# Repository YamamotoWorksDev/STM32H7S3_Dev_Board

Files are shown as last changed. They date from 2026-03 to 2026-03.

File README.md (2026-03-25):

# STM32H7S3 Development Board (rev.C)
This board is a development board featuring the STM32H7S3Z8T MCU.

## How to buy
- [Tindie(International)](https://www.tindie.com/products/41582/)
- [BASE(Japan)](https://miyworks.base.shop/items/135242611)

## Specifications
- MCU specs.
  - STMicroelectronics [STM32H7S3Z8T](https://www.st.com/en/microcontrollers-microprocessors/stm32h7s3z8.html)(Arm Cortex-M7 Core/600MHz max)
  - External Crystal Oscilator(24MHz)
  - External FLASH(256Mbits OctoSPI)
  - USB type-C(USB2.0 High-Speed supported)
  - [UF2 bootloader](https://github.com/yamamo2shun1/JUMBLEQ/tree/main/STM32CubeIDE/MX25UW25645GXDI00_STM32H7S3Z8T)

- DSP specs.
  - Analog Devices [ADAU1466](https://www.analog.com/en/products/adau1466.html)(SigmaDSP Core/294.912MHz max)

## Pinout
JUMBLEQ_main_pinout_revC

## Size


## Byte Options
XSPI1_HSLV
DTCM_AXI_SHARE

## Application Example
- [JUMBLEQ](https://github.com/yamamo2shun1/JUMBLEQ)

## Photo
overall
top

## License
The hardware design files in this repository are licensed under the
**CERN Open Hardware Licence Version 2 - Permissive (CERN-OHL-P-2.0)**.

Unless otherwise stated, the following are treated as hardware design files covered by CERN-OHL-P-2.0:

- KiCad schematic files
- PCB layout files

A copy of the license text is provided in the `LICENSE` file.

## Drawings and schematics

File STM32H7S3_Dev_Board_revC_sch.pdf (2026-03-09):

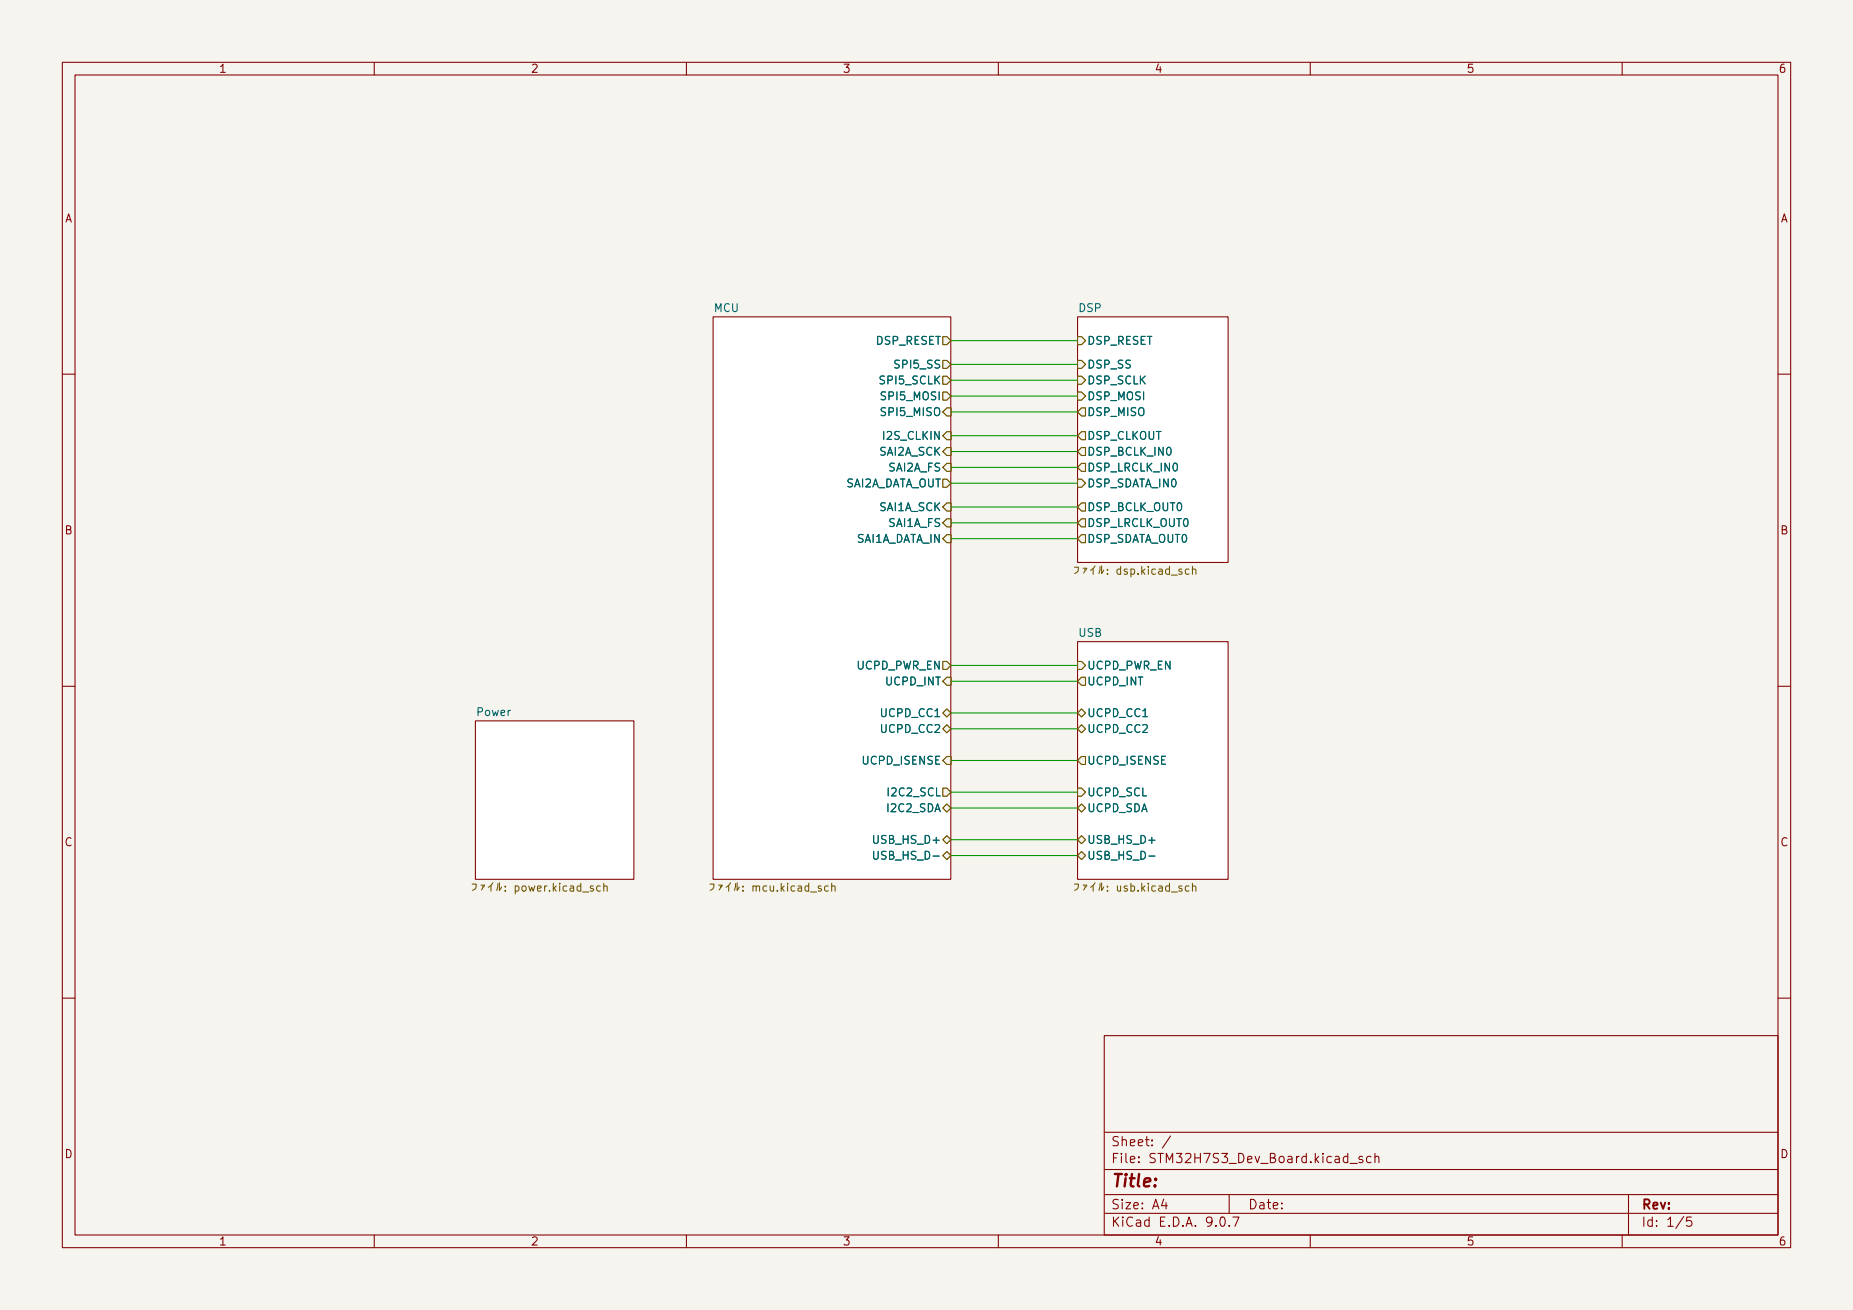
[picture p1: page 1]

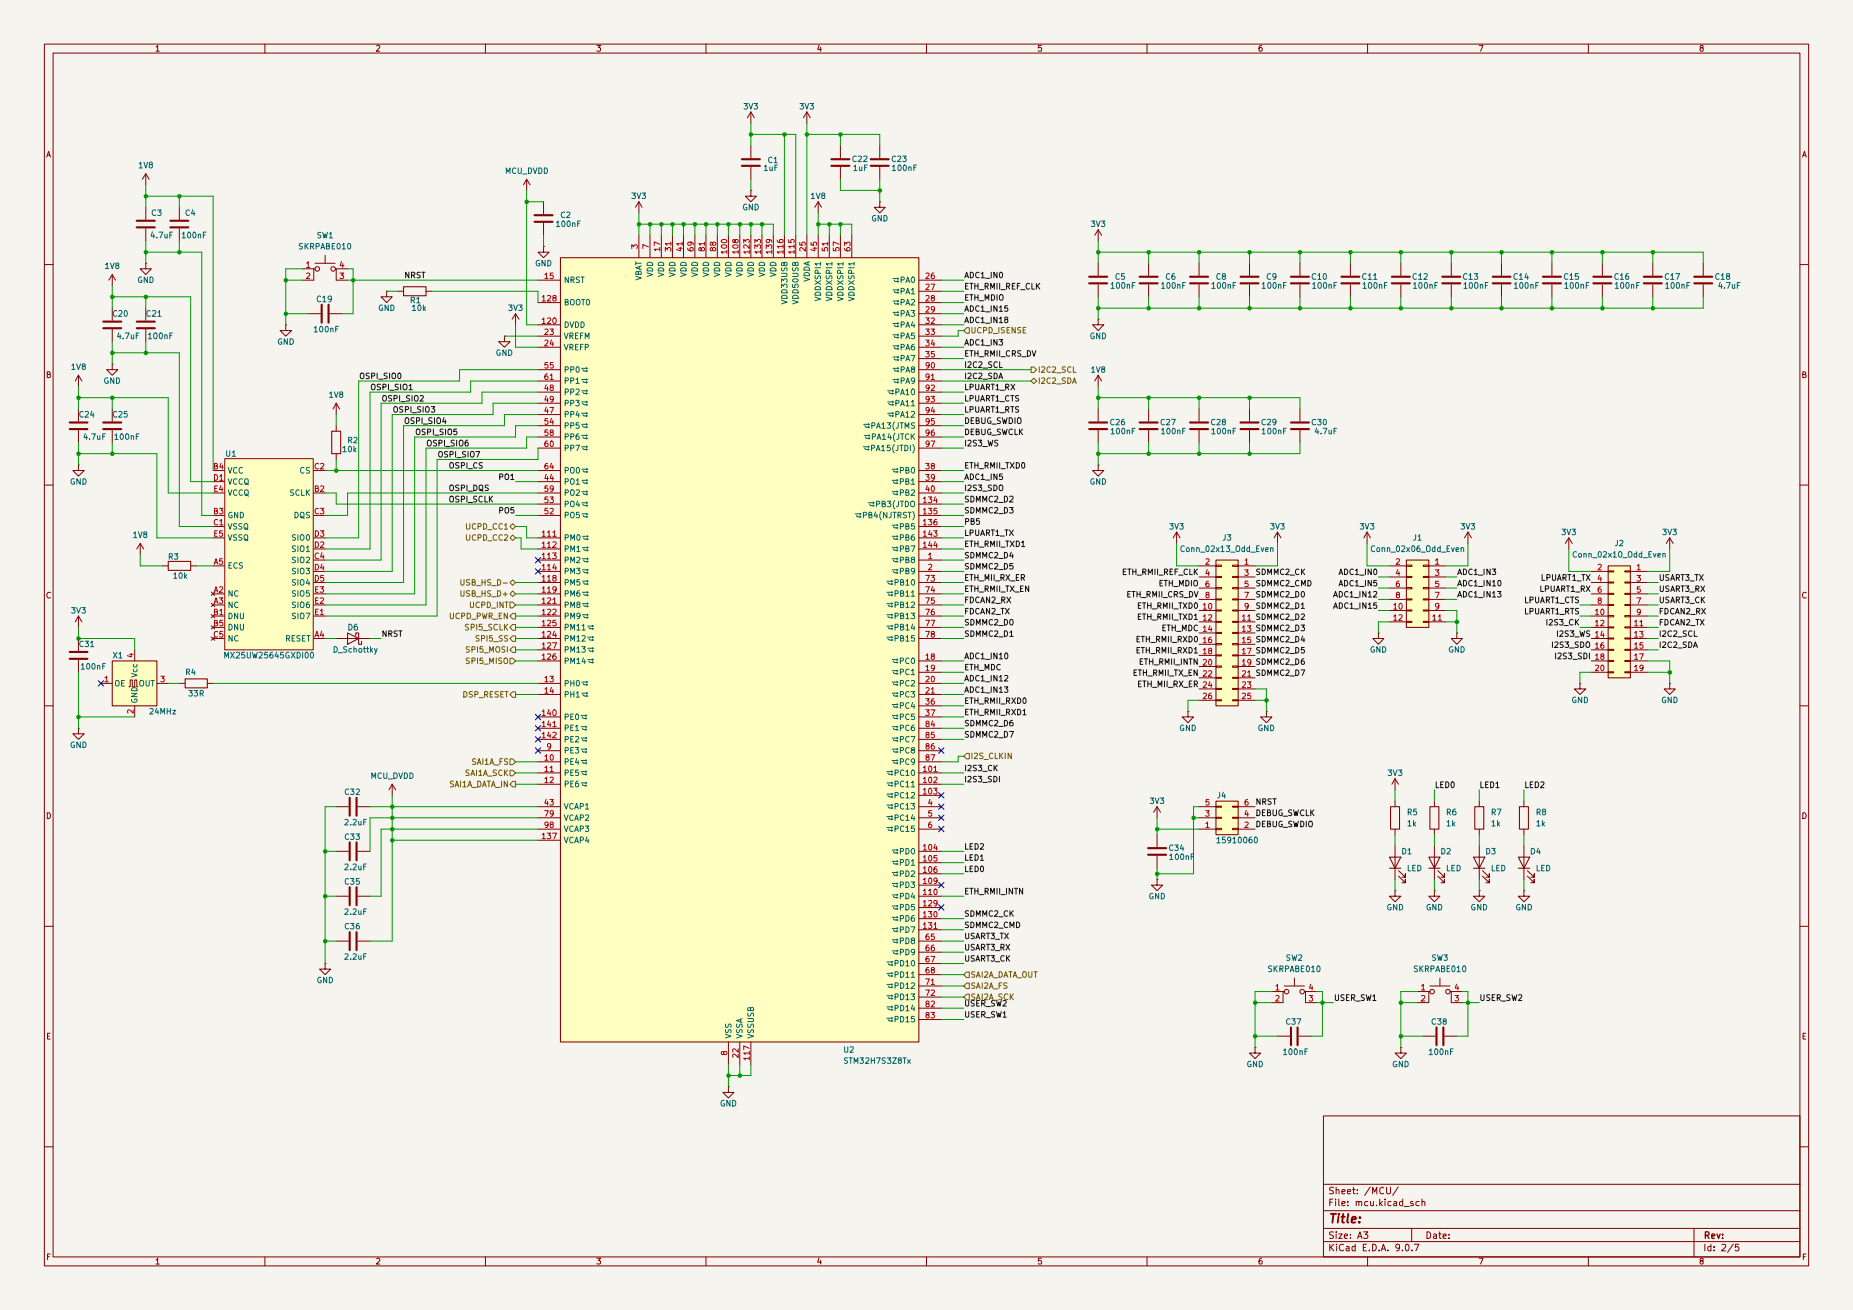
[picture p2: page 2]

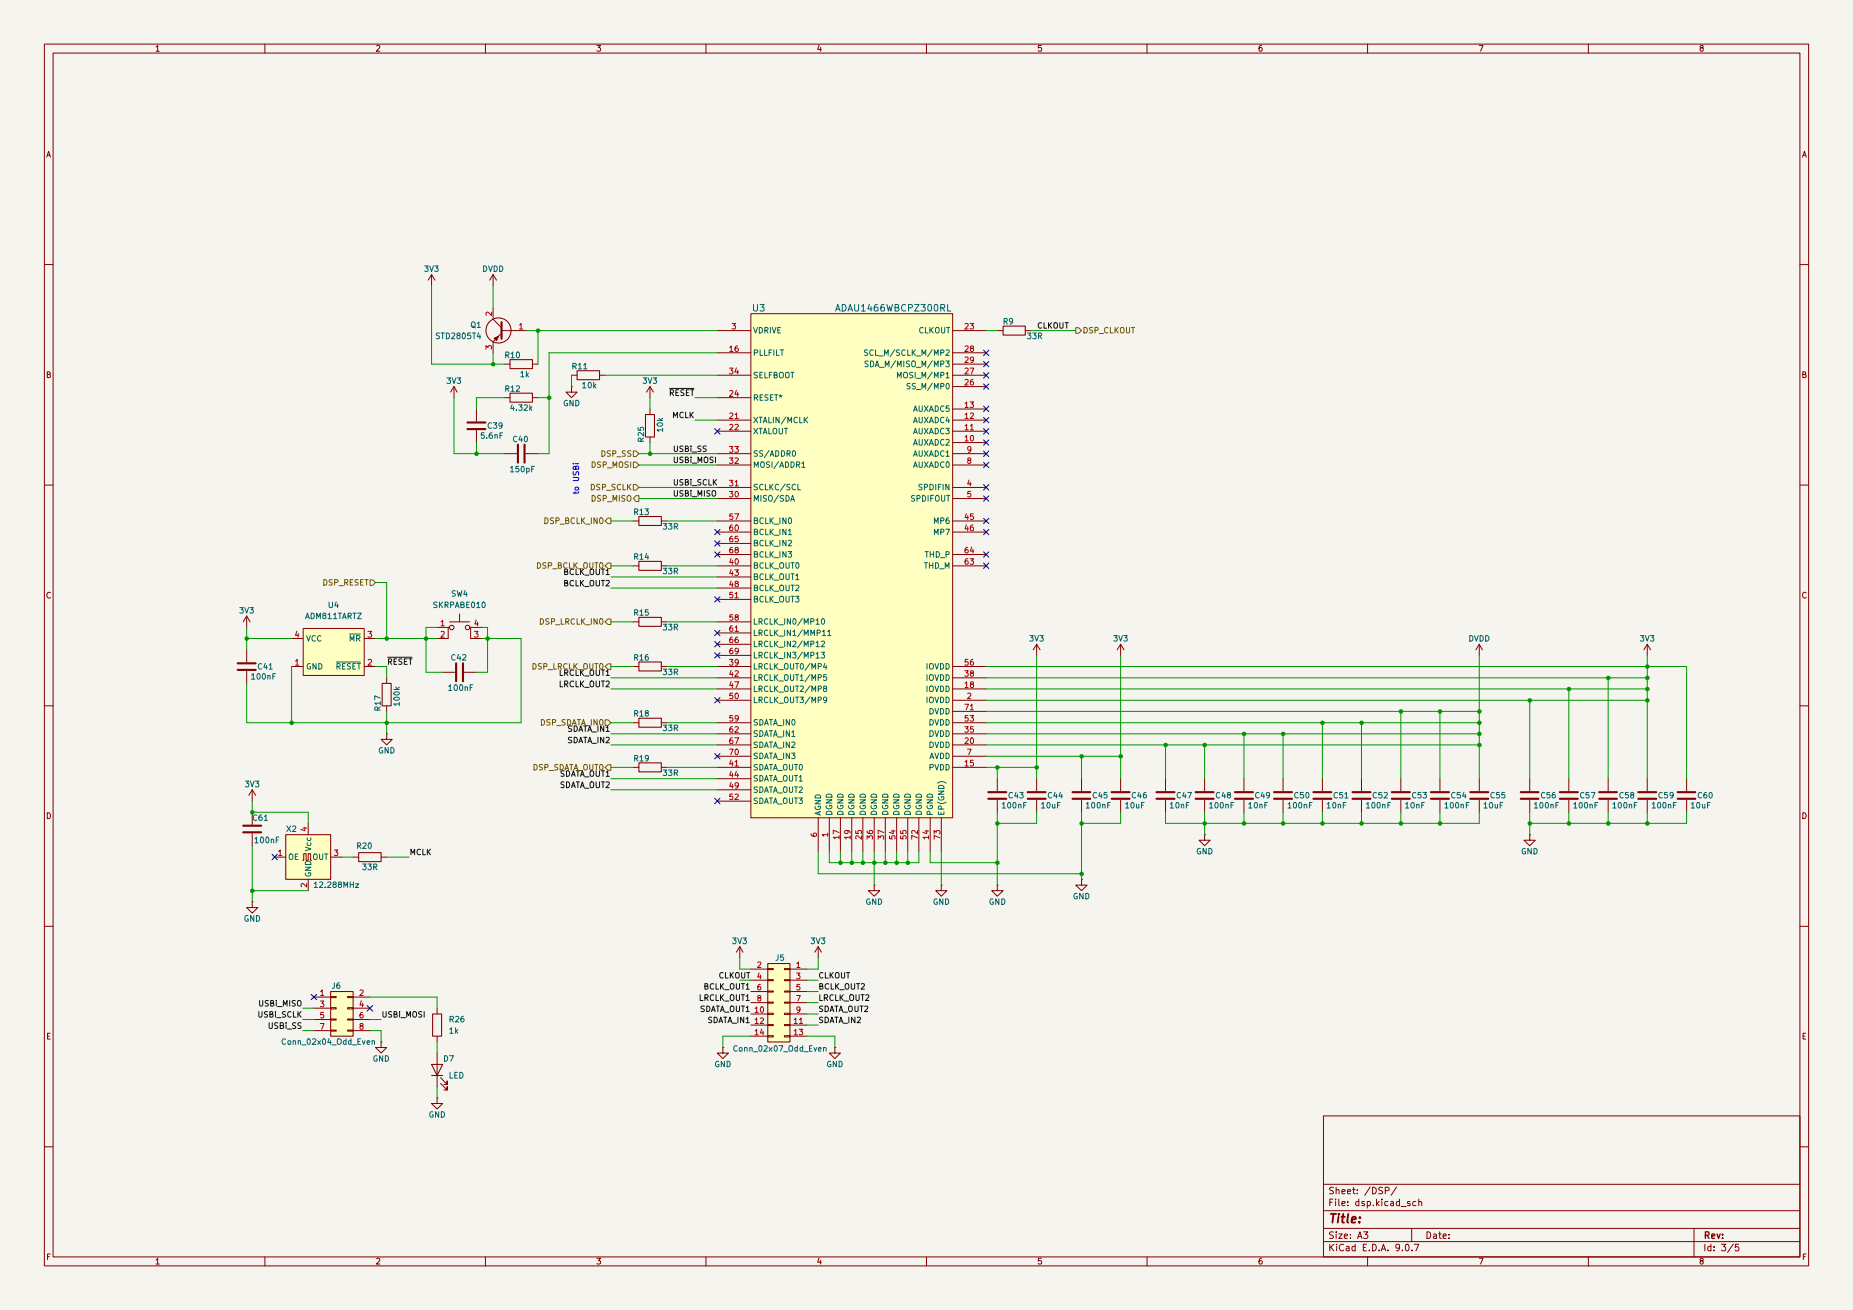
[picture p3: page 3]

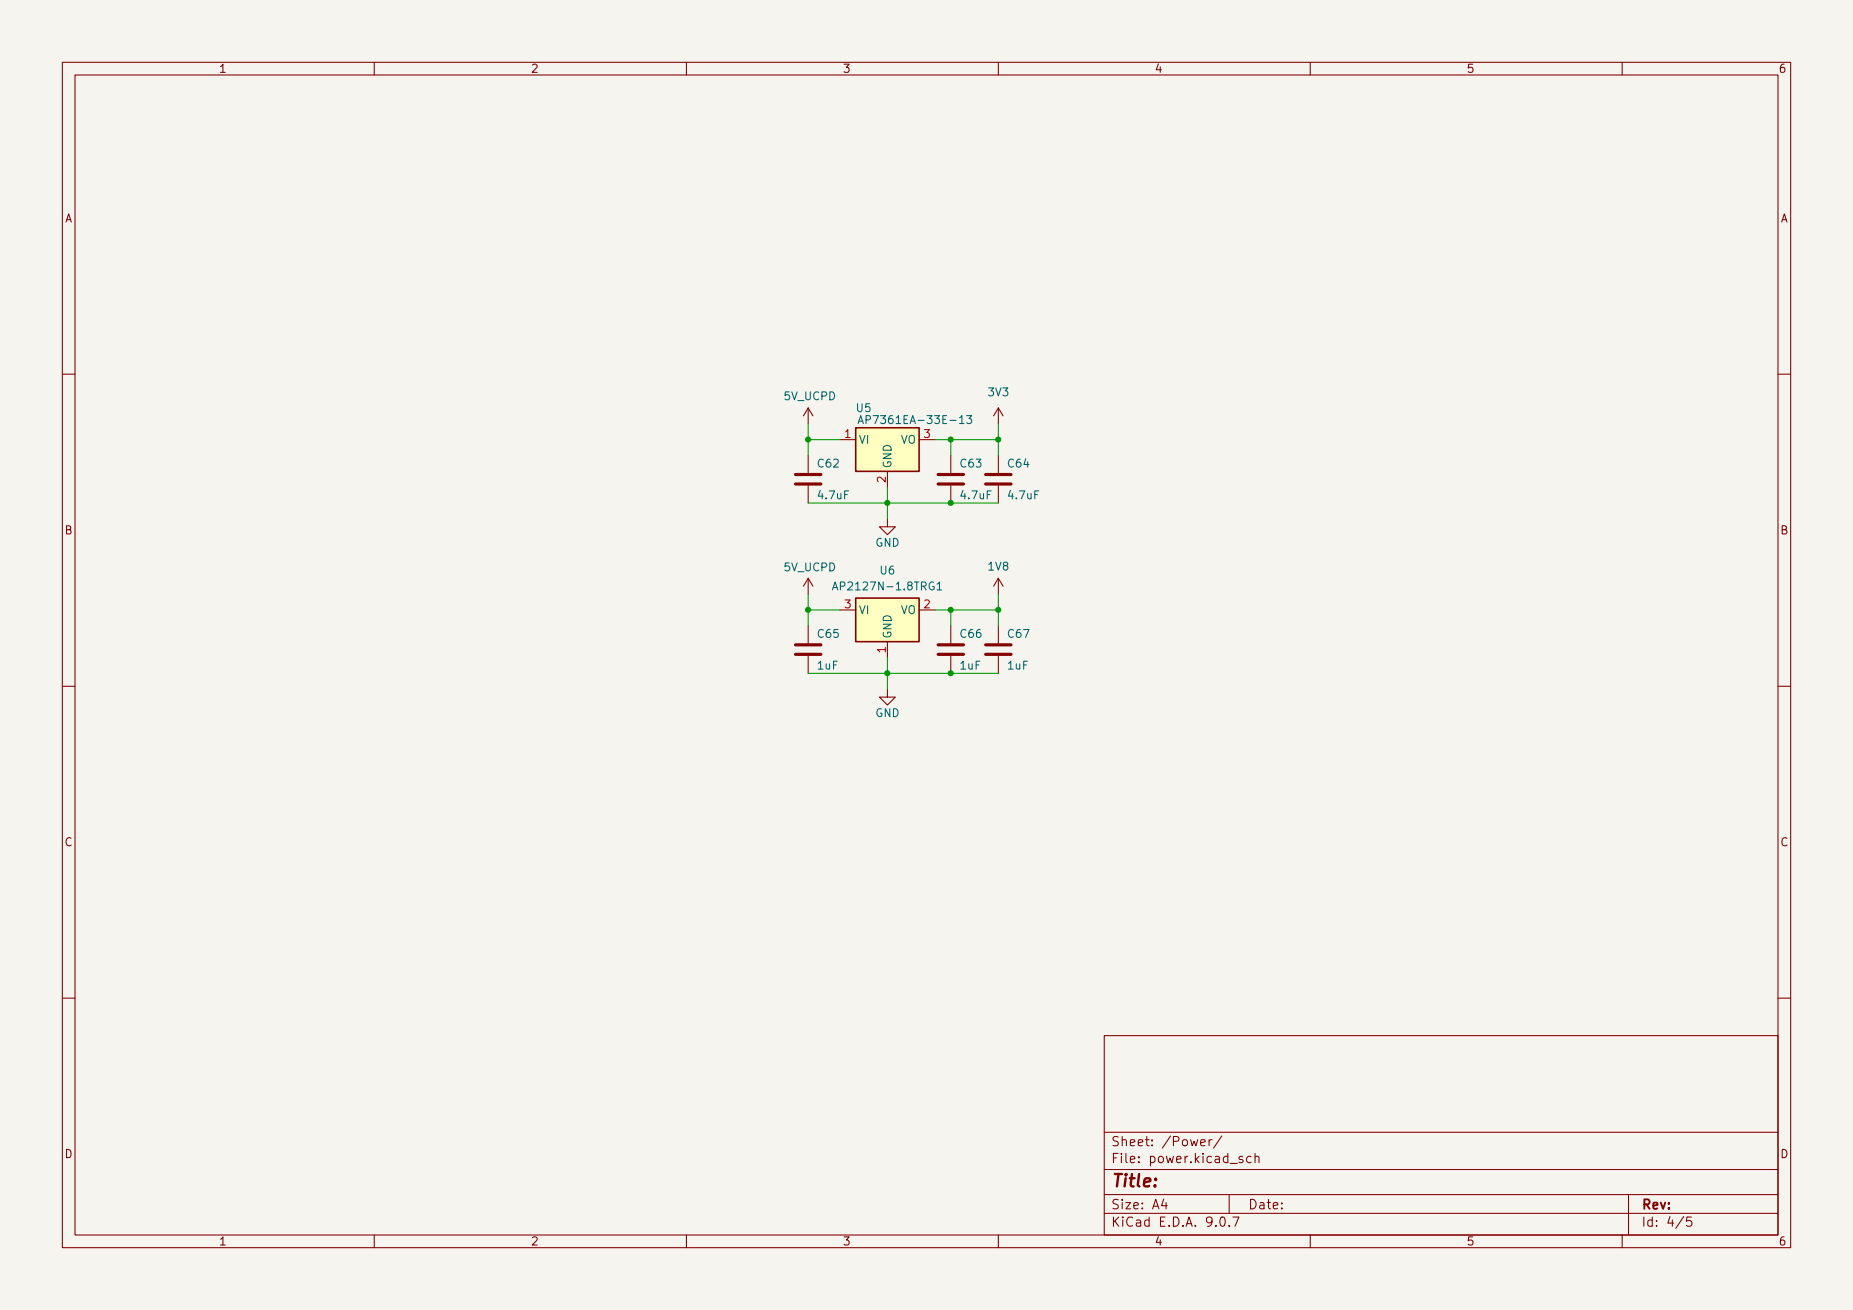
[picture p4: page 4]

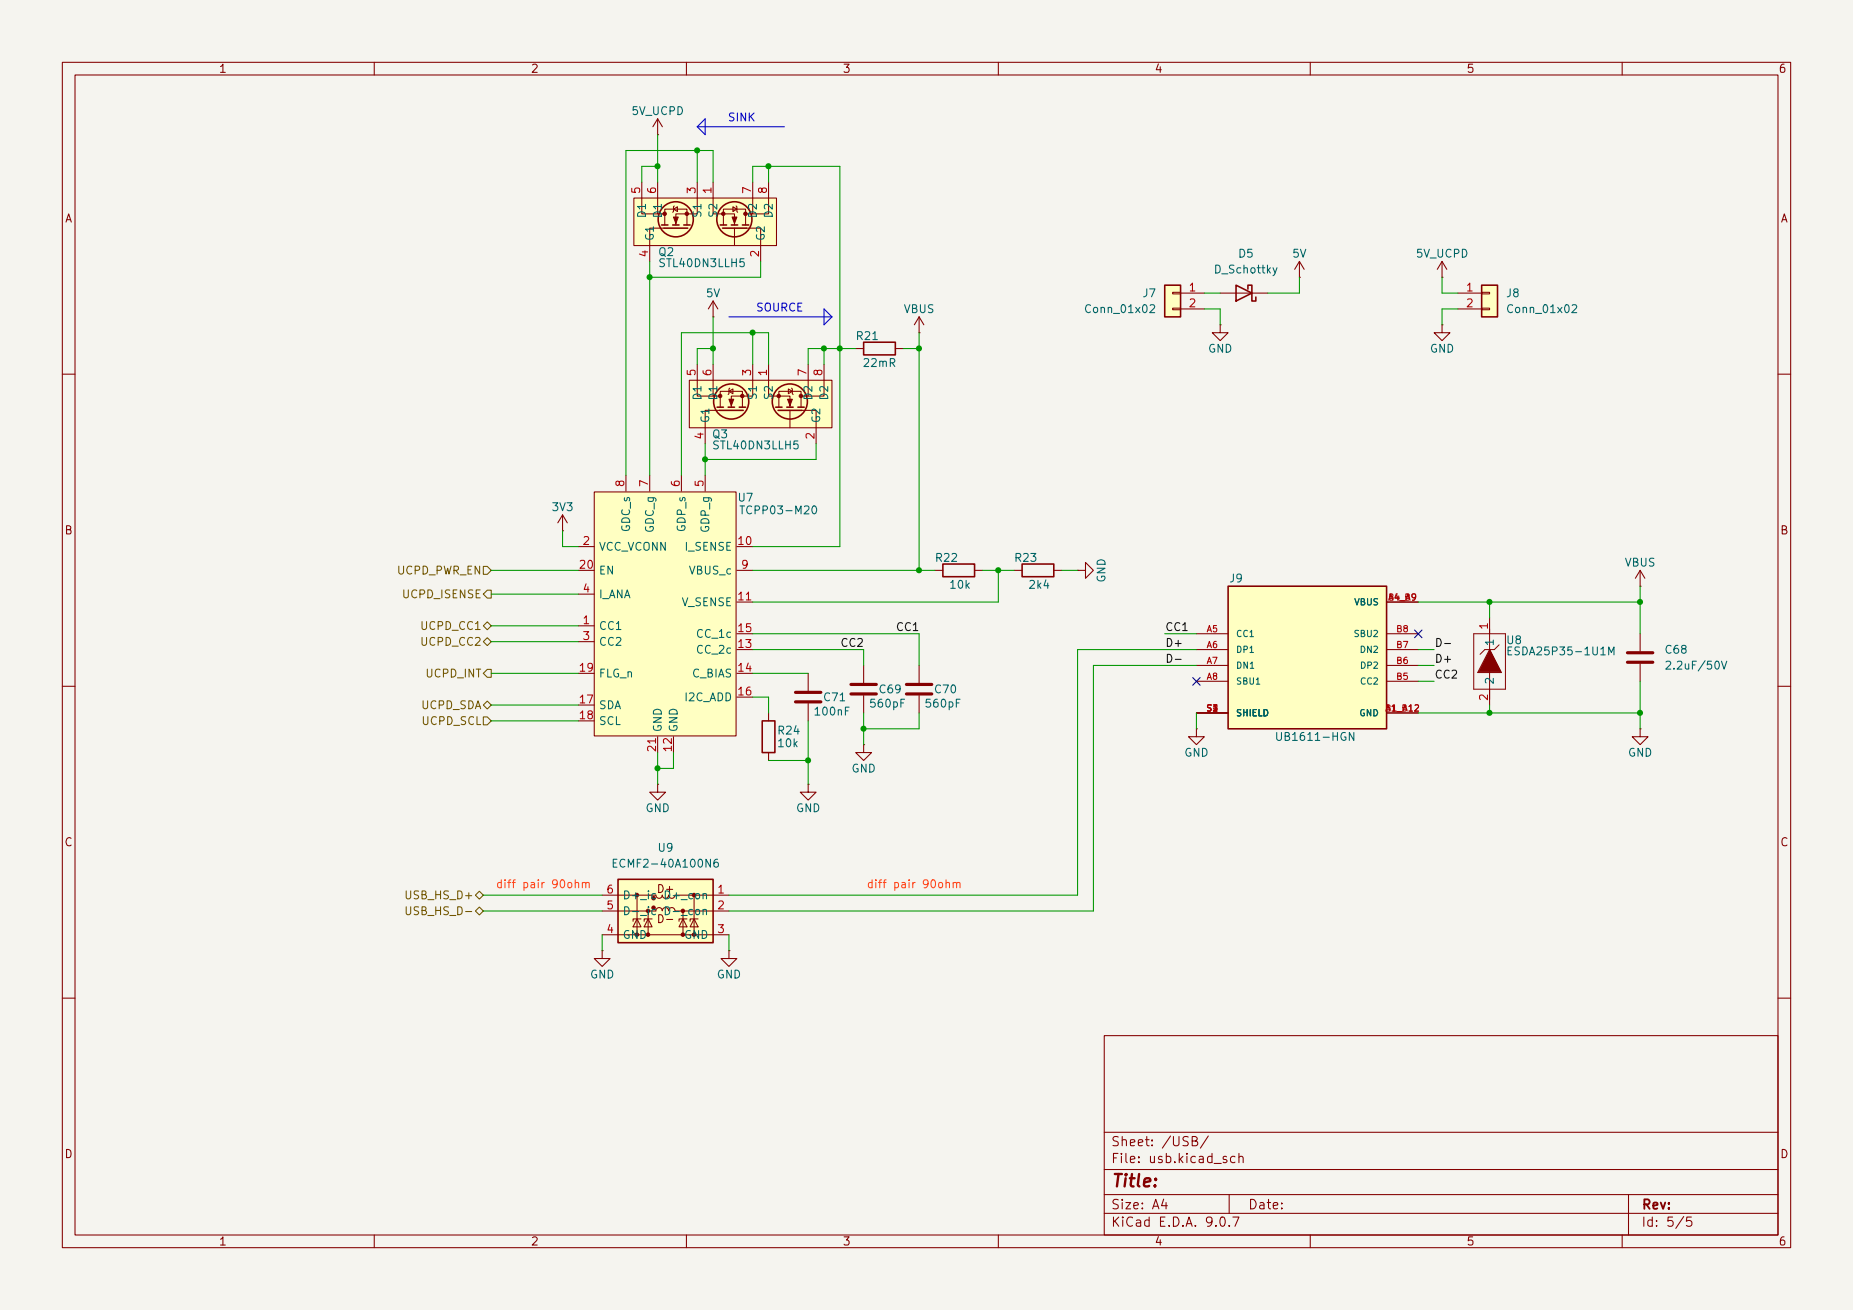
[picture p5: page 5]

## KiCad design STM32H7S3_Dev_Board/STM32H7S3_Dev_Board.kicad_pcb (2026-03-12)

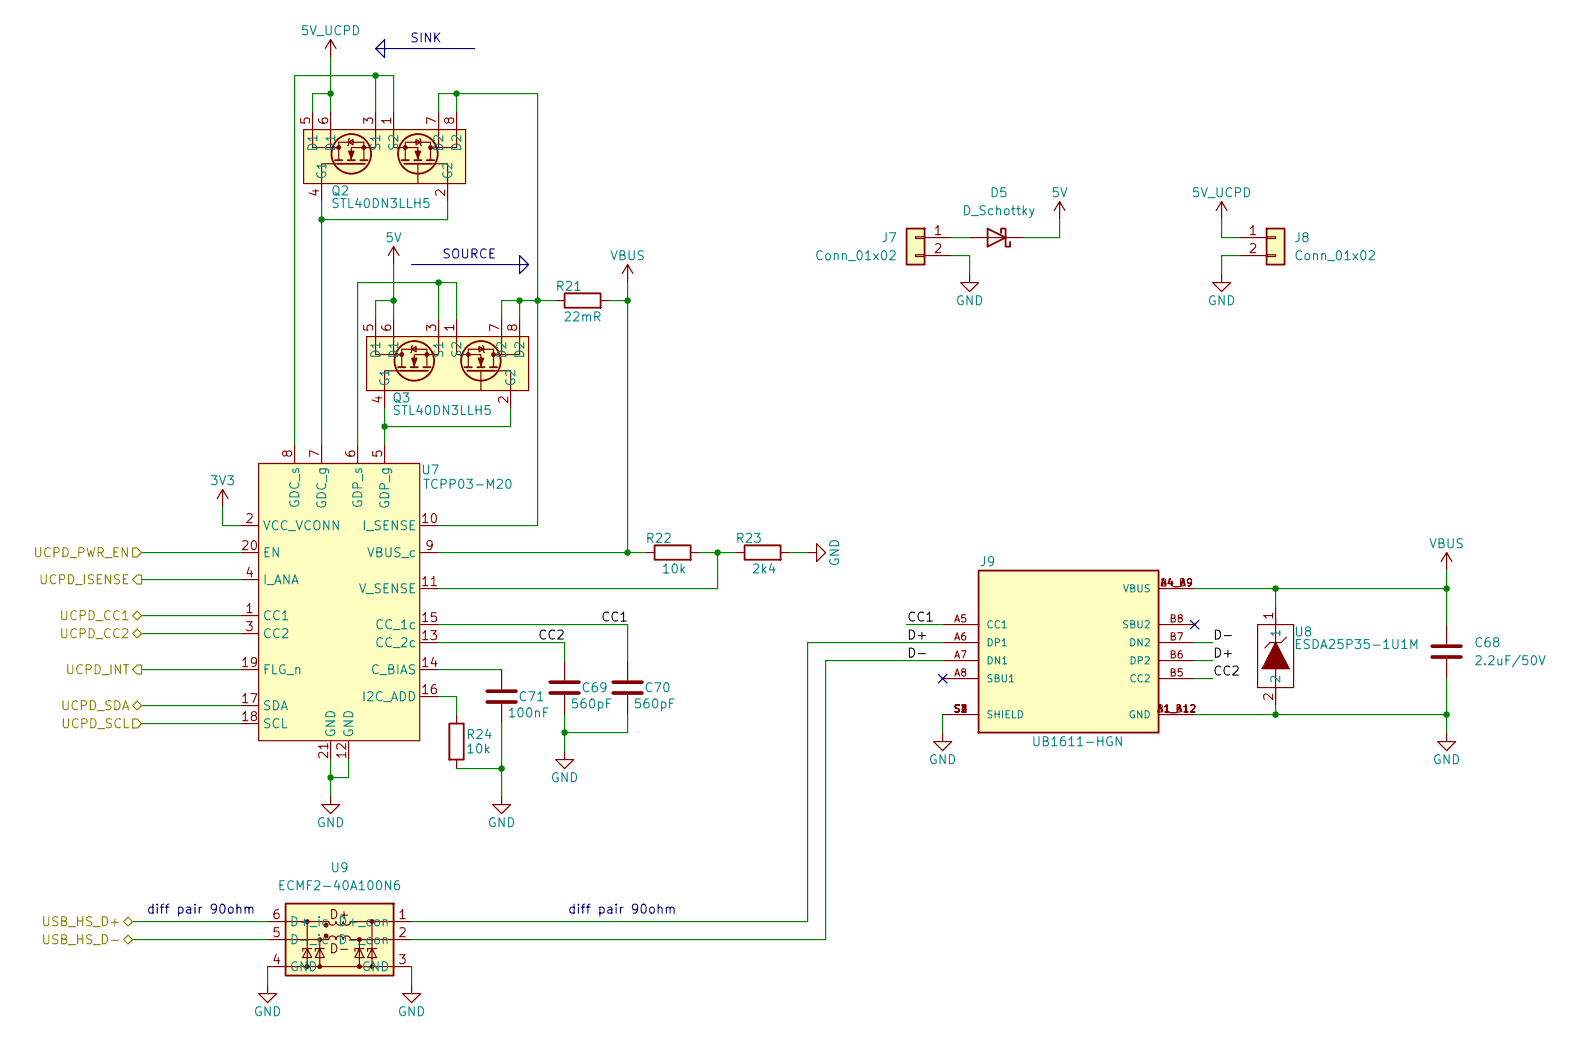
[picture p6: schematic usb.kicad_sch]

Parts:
C68: 2.2uF/50V; C_0603_1608Metric
C69, C70: 560pF; C_0201_0603Metric
C71: 100nF; C_0201_0603Metric
D5: D_Schottky; D_PowerDI-123
J7, J8: Conn_01x02; JST_PH_S2B-PH-K_1x02_P2.00mm_Horizontal
J9: UB1611-HGN; Gangyuan_UB1611-HGN; PARTREV B
Q2, Q3: STL40DN3LLH5; SON_DN3LLH5_STM
R21: 22mR; R_0603_1608Metric
R22, R24: 10k; R_0201_0603Metric
R23: 2k4; R_0201_0603Metric
U7: TCPP03-M20; QFN-20L_4.0X4.0X0.75_STM
U8: ESDA25P35-1U1M; QFN1610_STM
U9: ECMF2-40A100N6; QFN6L_ECMF2_STM

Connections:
3V3: U7.2 (VCC_VCONN); also elsewhere on the board
5V: D5.1 (K), Q3.5 (D1), Q3.6 (D1)
5V_UCPD: J8.1, Q2.5 (D1), Q2.6 (D1); also elsewhere on the board
/MCU/I2C2_SCL: U7.18 (SCL); also elsewhere on the board
/MCU/I2C2_SDA: U7.17 (SDA); also elsewhere on the board
/MCU/UCPD_CC1: U7.1 (CC1); also elsewhere on the board
/MCU/UCPD_CC2: U7.3 (CC2); also elsewhere on the board
/MCU/UCPD_INT: U7.19 (FLG_n); also elsewhere on the board
/MCU/UCPD_ISENSE: U7.4 (I_ANA); also elsewhere on the board
/MCU/UCPD_PWR_EN: U7.20 (EN); also elsewhere on the board
/MCU/USB_HS_D+: U9.6 (D+_ic); also elsewhere on the board
/MCU/USB_HS_D-: U9.5 (D-_ic); also elsewhere on the board
/USB/CC1: C70.1, J9.A5 (CC1), U7.15 (CC_1c)
/USB/CC2: C69.1, J9.B5 (CC2), U7.13 (CC_2c)
/USB/D+: J9.A6 (DP1), J9.B6 (DP2), U9.1 (D+_con)
/USB/D-: J9.A7 (DN1), J9.B7 (DN2), U9.2 (D-_con)
GND: C68.2, C69.2, C70.2, C71.2, J7.2, J8.2, J9.A1_B12 (GND), J9.B1_A12 (GND), J9.S1 (SHIELD), J9.S2 (SHIELD), J9.S3 (SHIELD), J9.S4 (SHIELD), R23.2, R24.2, U7.12 (GND), U7.21 (GND), U8.2, U9.3 (GND), U9.4 (GND); also elsewhere on the board
unnamed: D5.2 (A), J7.1
unnamed: Q2.2 (G2), Q2.4 (G1), U7.7 (GDC_g)
unnamed: Q2.1 (S2), Q2.3 (S1), U7.8 (GDC_s)
unnamed: Q3.2 (G2), Q3.4 (G1), U7.5 (GDP_g)
unnamed: Q3.1 (S2), Q3.3 (S1), U7.6 (GDP_s)
unnamed: C71.1, U7.14 (C_BIAS)
unnamed: R24.1, U7.16 (I2C_ADD)
unnamed: Q2.7 (D2), Q2.8 (D2), Q3.7 (D2), Q3.8 (D2), R21.1, U7.10 (I_SENSE)
unnamed: R22.2, R23.1, U7.11 (V_SENSE)
VBUS: C68.1, J9.A4_B9 (VBUS), J9.B4_A9 (VBUS), R21.2, R22.1, U7.9 (VBUS_c), U8.1

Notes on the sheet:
SOURCE
diff pair 90ohm
SINK

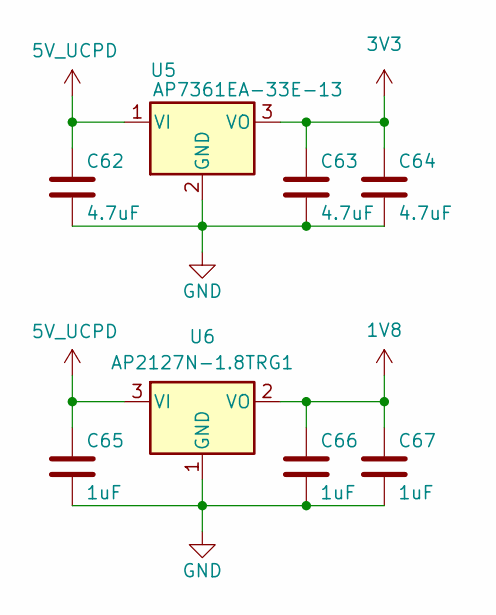
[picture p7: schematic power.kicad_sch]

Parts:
C62, C63, C64: 4.7uF; C_0603_1608Metric
C65, C66, C67: 1uF; C_0603_1608Metric
U5: AP7361EA-33E-13; SOT-223-3_TabPin2
U6: AP2127N-1.8TRG1; SOT-23

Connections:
1V8: C66.1, C67.1, U6.2 (VO); also elsewhere on the board
3V3: C63.1, C64.1, U5.3 (VO); also elsewhere on the board
5V_UCPD: C62.1, C65.1, U5.1 (VI), U6.3 (VI); also elsewhere on the board
GND: C62.2, C63.2, C64.2, C65.2, C66.2, C67.2, U5.2 (GND), U6.1 (GND); also elsewhere on the board

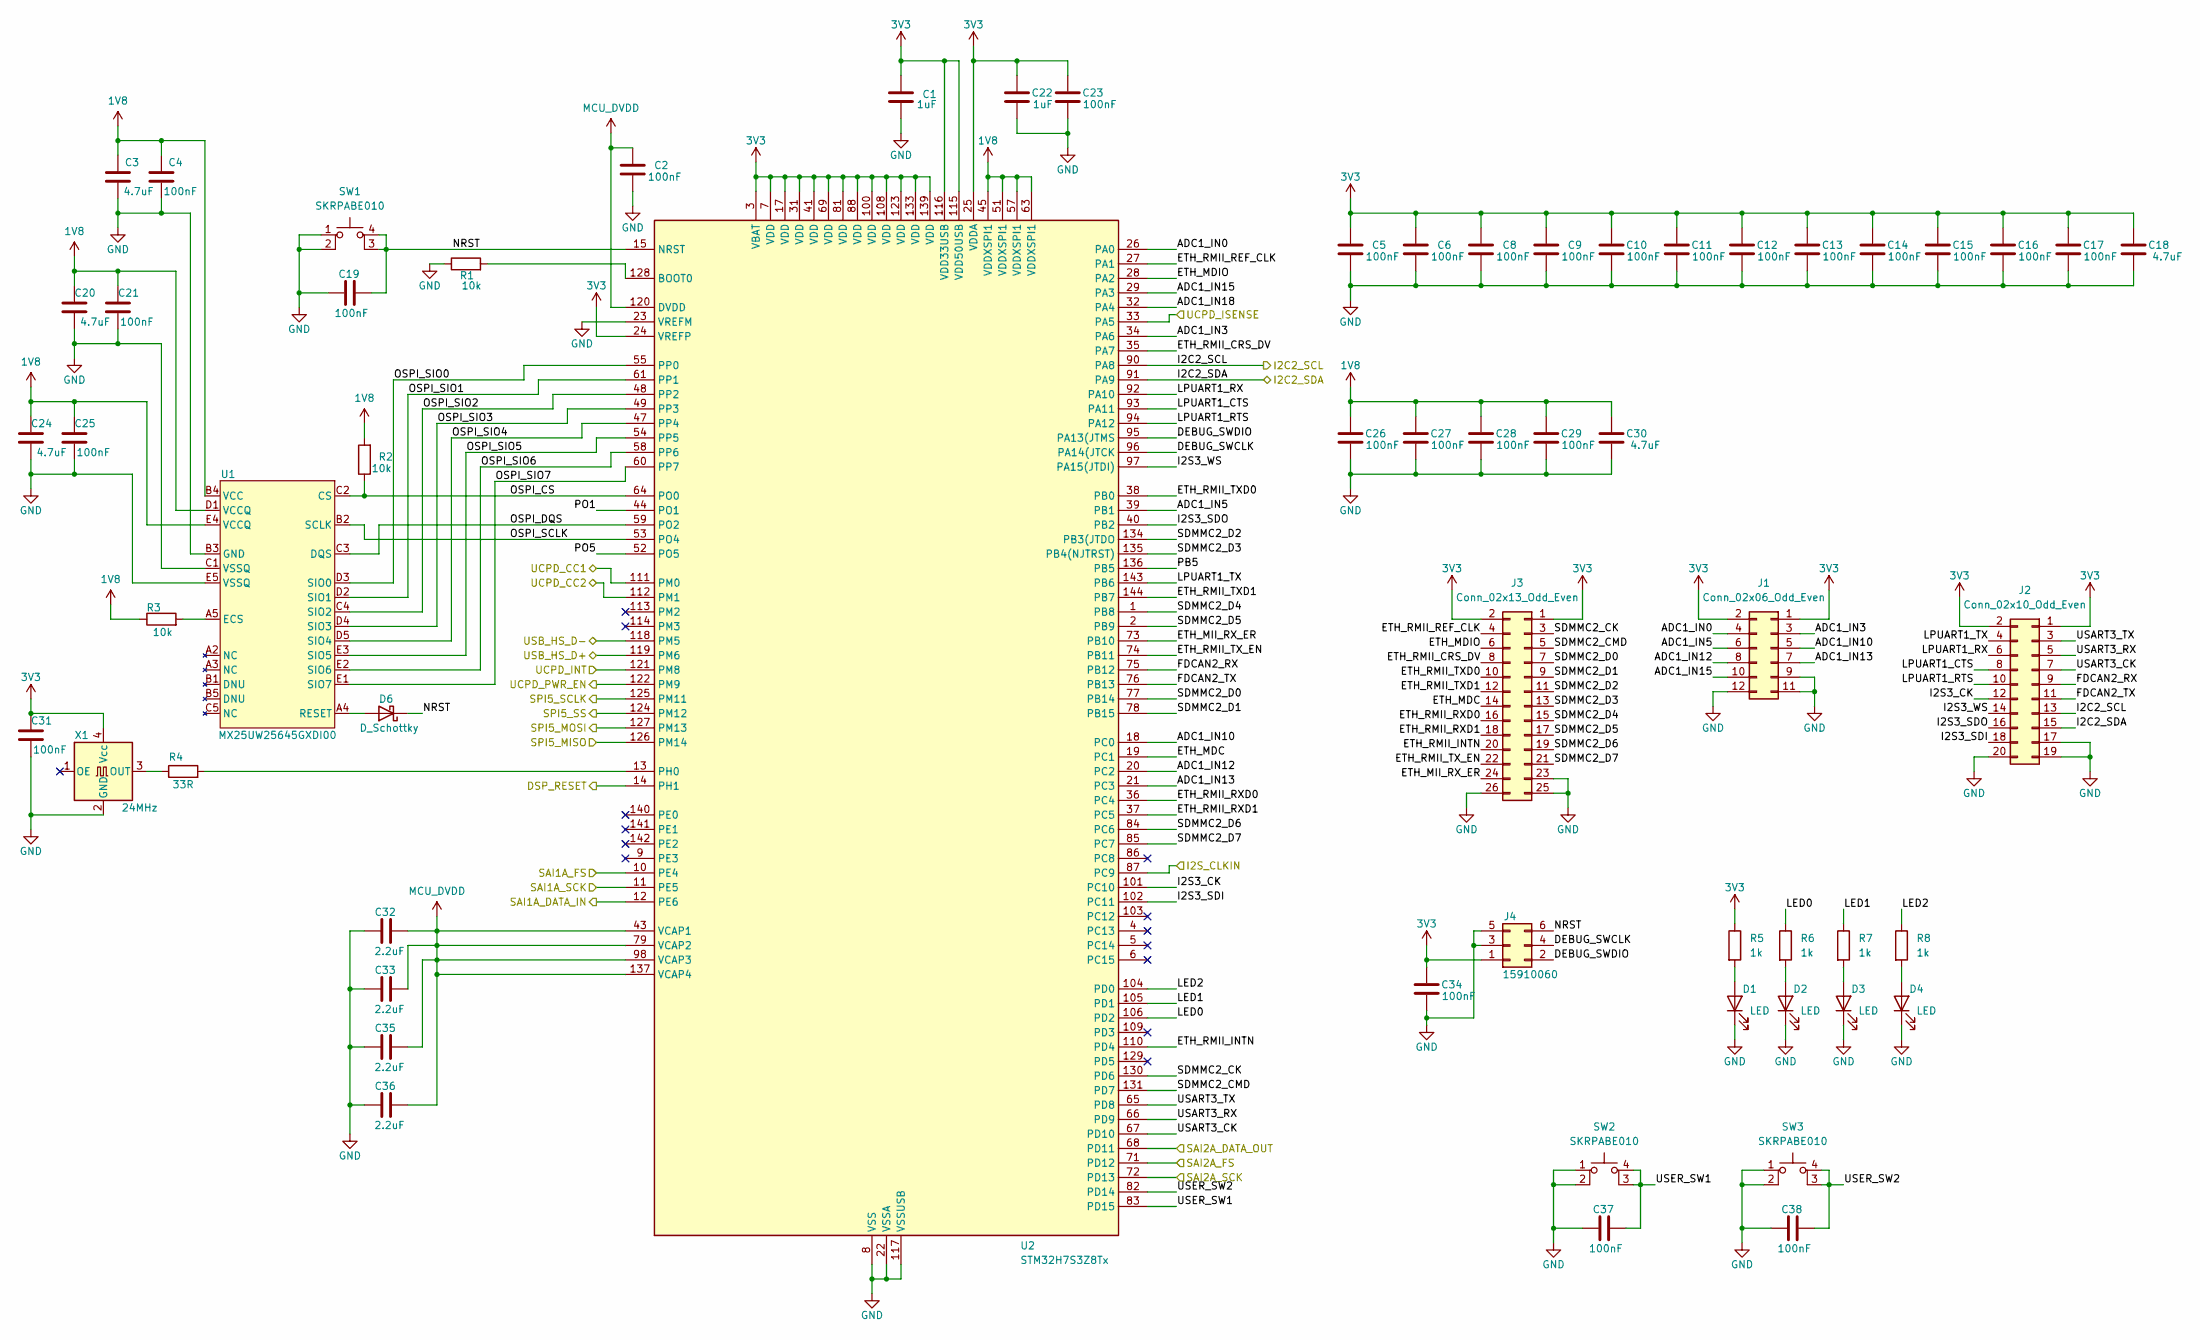
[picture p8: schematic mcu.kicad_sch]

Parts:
C1, C22: 1uF; C_0402_1005Metric
C2, C5, C6, C8, C9, C10, C11, C12, C13, C14, C15, C16, C17, C19, C23, C26, C27, C28, C29, C31, C34, C37, C38: 100nF; C_0201_0603Metric
C3, C18, C20, C24, C30: 4.7uF; C_0402_1005Metric
C4, C21, C25: 100nF; C_0402_1005Metric
C32, C33, C35, C36: 2.2uF; C_0402_1005Metric
D1, D2, D3, D4: LED; LED_0603_1608Metric
D6: D_Schottky; D_SOD-523
J1: Conn_02x06_Odd_Even; PinSocket_2x06_P2.54mm_Vertical
J2: Conn_02x10_Odd_Even; PinSocket_2x10_P2.54mm_Vertical
J3: Conn_02x13_Odd_Even; PinSocket_2x13_P2.54mm_Vertical
J4: 15910060; PinHeader_2x03_P2.54mm_Vertical
R1, R2, R3: 10k; R_0201_0603Metric
R4: 33R; R_0201_0603Metric
R5, R6, R7, R8: 1k; R_0201_0603Metric
SW1, SW2, SW3: SKRPABE010
U1: MX25UW25645GXDI00; BGA24C100P5X5_800X600X120
U2: STM32H7S3Z8Tx; LQFP-144_20x20mm_P0.5mm
X1: 24MHz; Oscillator_SMD_SeikoEpson_SG210-4Pin_2.5x2.0mm

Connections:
1V8: C3.2, C4.2, C20.2, C21.2, C24.2, C25.2, C26.2, C27.2, C28.2, C29.2, C30.2, R2.2, R3.1, U1.B4 (VCC), U1.D1 (VCCQ), U1.E4 (VCCQ), U2.45 (VDDXSPI1), U2.51 (VDDXSPI1), U2.57 (VDDXSPI1), U2.63 (VDDXSPI1); also elsewhere on the board
3V3: C1.2, C5.2, C6.2, C8.2, C9.2, C10.2, C11.2, C12.2, C13.2, C14.2, C15.2, C16.2, C17.2, C18.2, C22.2, C23.2, C31.2, C34.2, J1.1, J1.2, J2.1, J2.2, J3.1, J3.2, J4.1, R5.1, U2.3 (VBAT), U2.7 (VDD), U2.17 (VDD), U2.24 (VREFP), U2.25 (VDDA), U2.31 (VDD), U2.41 (VDD), U2.69 (VDD), U2.81 (VDD), U2.88 (VDD), U2.100 (VDD), U2.108 (VDD), U2.115 (VDD50USB), U2.116 (VDD33USB), U2.123 (VDD), U2.133 (VDD), U2.139 (VDD), X1.4 (Vcc); also elsewhere on the board
/DSP/CLKOUT: U2.87 (PC9); also elsewhere on the board
/DSP/DSP_BCLK_IN0: U2.72 (PD13); also elsewhere on the board
/DSP/DSP_BCLK_OUT0: U2.11 (PE5); also elsewhere on the board
/DSP/DSP_LRCLK_IN0: U2.71 (PD12); also elsewhere on the board
/DSP/DSP_LRCLK_OUT0: U2.10 (PE4); also elsewhere on the board
/DSP/DSP_RESET: U2.14 (PH1); also elsewhere on the board
/DSP/DSP_SDATA_IN0: U2.68 (PD11); also elsewhere on the board
/DSP/DSP_SDATA_OUT0: U2.12 (PE6); also elsewhere on the board
/DSP/USBi_MISO: U2.126 (PM14); also elsewhere on the board
/DSP/USBi_MOSI: U2.127 (PM13); also elsewhere on the board
/DSP/USBi_SCLK: U2.125 (PM11); also elsewhere on the board
/DSP/USBi_SS: U2.124 (PM12); also elsewhere on the board
/MCU/ADC1_IN0: J1.4, U2.26 (PA0)
/MCU/ADC1_IN3: J1.3, U2.34 (PA6)
/MCU/ADC1_IN5: J1.6, U2.39 (PB1)
/MCU/ADC1_IN10: J1.5, U2.18 (PC0)
/MCU/ADC1_IN12: J1.8, U2.20 (PC2)
/MCU/ADC1_IN13: J1.7, U2.21 (PC3)
/MCU/ADC1_IN15: J1.10, U2.29 (PA3)
/MCU/ADC1_IN18: U2.32 (PA4)
/MCU/DEBUG_SWCLK: J4.4, U2.96 (PA14(JTCK)
/MCU/DEBUG_SWDIO: J4.2, U2.95 (PA13(JTMS)
/MCU/ETH_MDC: J3.14, U2.19 (PC1)
/MCU/ETH_MDIO: J3.6, U2.28 (PA2)
/MCU/ETH_MII_RX_ER: J3.24, U2.73 (PB10)
/MCU/ETH_RMII_CRS_DV: J3.8, U2.35 (PA7)
/MCU/ETH_RMII_INTN: J3.20, U2.110 (PD4)
/MCU/ETH_RMII_REF_CLK: J3.4, U2.27 (PA1)
/MCU/ETH_RMII_RXD0: J3.16, U2.36 (PC4)
/MCU/ETH_RMII_RXD1: J3.18, U2.37 (PC5)
/MCU/ETH_RMII_TXD0: J3.10, U2.38 (PB0)
/MCU/ETH_RMII_TXD1: J3.12, U2.144 (PB7)
/MCU/ETH_RMII_TX_EN: J3.22, U2.74 (PB11)
/MCU/FDCAN2_RX: J2.9, U2.75 (PB12)
/MCU/FDCAN2_TX: J2.11, U2.76 (PB13)
/MCU/I2C2_SCL: J2.13, U2.90 (PA8); also elsewhere on the board
/MCU/I2C2_SDA: J2.15, U2.91 (PA9); also elsewhere on the board
/MCU/I2S3_CK: J2.12, U2.101 (PC10)
/MCU/I2S3_SDI: J2.18, U2.102 (PC11)
/MCU/I2S3_SDO: J2.16, U2.40 (PB2)
/MCU/I2S3_WS: J2.14, U2.97 (PA15(JTDI))
/MCU/LED0: R6.1, U2.106 (PD2)
/MCU/LED1: R7.1, U2.105 (PD1)
/MCU/LED2: R8.1, U2.104 (PD0)
/MCU/LPUART1_CTS: J2.8, U2.93 (PA11)
/MCU/LPUART1_RTS: J2.10, U2.94 (PA12)
/MCU/LPUART1_RX: J2.6, U2.92 (PA10)
/MCU/LPUART1_TX: J2.4, U2.143 (PB6)
/MCU/NRST: C19.2, D6.1 (K), J4.6, SW1.3 (K), SW1.4 (A), U2.15 (NRST)
/MCU/OSPI_CS: R2.1, U1.C2 (CS), U2.64 (PO0)
/MCU/OSPI_DQS: U1.C3 (DQS), U2.59 (PO2)
/MCU/OSPI_SCLK: U1.B2 (SCLK), U2.53 (PO4)
/MCU/OSPI_SIO0: U1.D3 (SIO0), U2.55 (PP0)
/MCU/OSPI_SIO1: U1.D2 (SIO1), U2.61 (PP1)
/MCU/OSPI_SIO2: U1.C4 (SIO2), U2.48 (PP2)
/MCU/OSPI_SIO3: U1.D4 (SIO3), U2.49 (PP3)
/MCU/OSPI_SIO4: U1.D5 (SIO4), U2.47 (PP4)
/MCU/OSPI_SIO5: U1.E3 (SIO5), U2.54 (PP5)
/MCU/OSPI_SIO6: U1.E2 (SIO6), U2.58 (PP6)
/MCU/OSPI_SIO7: U1.E1 (SIO7), U2.60 (PP7)
/MCU/PB5: U2.136 (PB5)
/MCU/PO1: U2.44 (PO1)
/MCU/PO5: U2.52 (PO5)
/MCU/SDMMC2_CK: J3.3, U2.130 (PD6)
/MCU/SDMMC2_CMD: J3.5, U2.131 (PD7)
/MCU/SDMMC2_D0: J3.7, U2.77 (PB14)
/MCU/SDMMC2_D1: J3.9, U2.78 (PB15)
/MCU/SDMMC2_D2: J3.11, U2.134 (PB3(JTDO)
/MCU/SDMMC2_D3: J3.13, U2.135 (PB4(NJTRST))
/MCU/SDMMC2_D4: J3.15, U2.1 (PB8)
/MCU/SDMMC2_D5: J3.17, U2.2 (PB9)
/MCU/SDMMC2_D6: J3.19, U2.84 (PC6)
/MCU/SDMMC2_D7: J3.21, U2.85 (PC7)
/MCU/UCPD_CC1: U2.111 (PM0); also elsewhere on the board
/MCU/UCPD_CC2: U2.112 (PM1); also elsewhere on the board
/MCU/UCPD_INT: U2.121 (PM8); also elsewhere on the board
/MCU/UCPD_ISENSE: U2.33 (PA5); also elsewhere on the board
/MCU/UCPD_PWR_EN: U2.122 (PM9); also elsewhere on the board
/MCU/USART3_CK: J2.7, U2.67 (PD10)
/MCU/USART3_RX: J2.5, U2.66 (PD9)
/MCU/USART3_TX: J2.3, U2.65 (PD8)
/MCU/USB_HS_D+: U2.119 (PM6); also elsewhere on the board
/MCU/USB_HS_D-: U2.118 (PM5); also elsewhere on the board
/MCU/USER_SW1: C37.2, SW2.3 (K), SW2.4 (A), U2.83 (PD15)
/MCU/USER_SW2: C38.2, SW3.3 (K), SW3.4 (A), U2.82 (PD14)
GND: C1.1, C2.1, C3.1, C4.1, C5.1, C6.1, C8.1, C9.1, C10.1, C11.1, C12.1, C13.1, C14.1, C15.1, C16.1, C17.1, C18.1, C19.1, C20.1, C21.1, C22.1, C23.1, C24.1, C25.1, C26.1, C27.1, C28.1, C29.1, C30.1, C31.1, C32.1, C33.1, C34.1, C35.1, C36.1, C37.1, C38.1, D1.1 (K), D2.1 (K), D3.1 (K), D4.1 (K), J1.9, J1.11, J1.12, J2.17, J2.19, J2.20, J3.23, J3.25, J3.26, J4.3, J4.5, R1.1, SW1.1, SW1.2, SW2.1, SW2.2, SW3.1, SW3.2, U1.B3 (GND), U1.C1 (VSSQ), U1.E5 (VSSQ), U2.8 (VSS), U2.16 (VSS), U2.22 (VSSA), U2.23 (VREFM), U2.30 (VSS), U2.42 (VSS), U2.46 (VSS), U2.50 (VSS), U2.56 (VSS), U2.62 (VSS), U2.70 (VSS), U2.80 (VSS), U2.89 (VSS), U2.99 (VSS), U2.107 (VSS), U2.117 (VSSUSB), U2.132 (VSS), U2.138 (VSS), X1.2 (GND); also elsewhere on the board
MCU_DVDD: C2.2, C32.2, C33.2, C35.2, C36.2, U2.43 (VCAP1), U2.79 (VCAP2), U2.98 (VCAP3), U2.120 (DVDD), U2.137 (VCAP4)
unnamed: D1.2 (A), R5.2
unnamed: D2.2 (A), R6.2
unnamed: D3.2 (A), R7.2
unnamed: D4.2 (A), R8.2
unnamed: D6.2 (A), U1.A4 (RESET)
unnamed: R3.2, U1.A5 (ECS)
unnamed: R1.2, U2.128 (BOOT0)
unnamed: R4.2, U2.13 (PH0)
unnamed: R4.1, X1.3 (OUT)

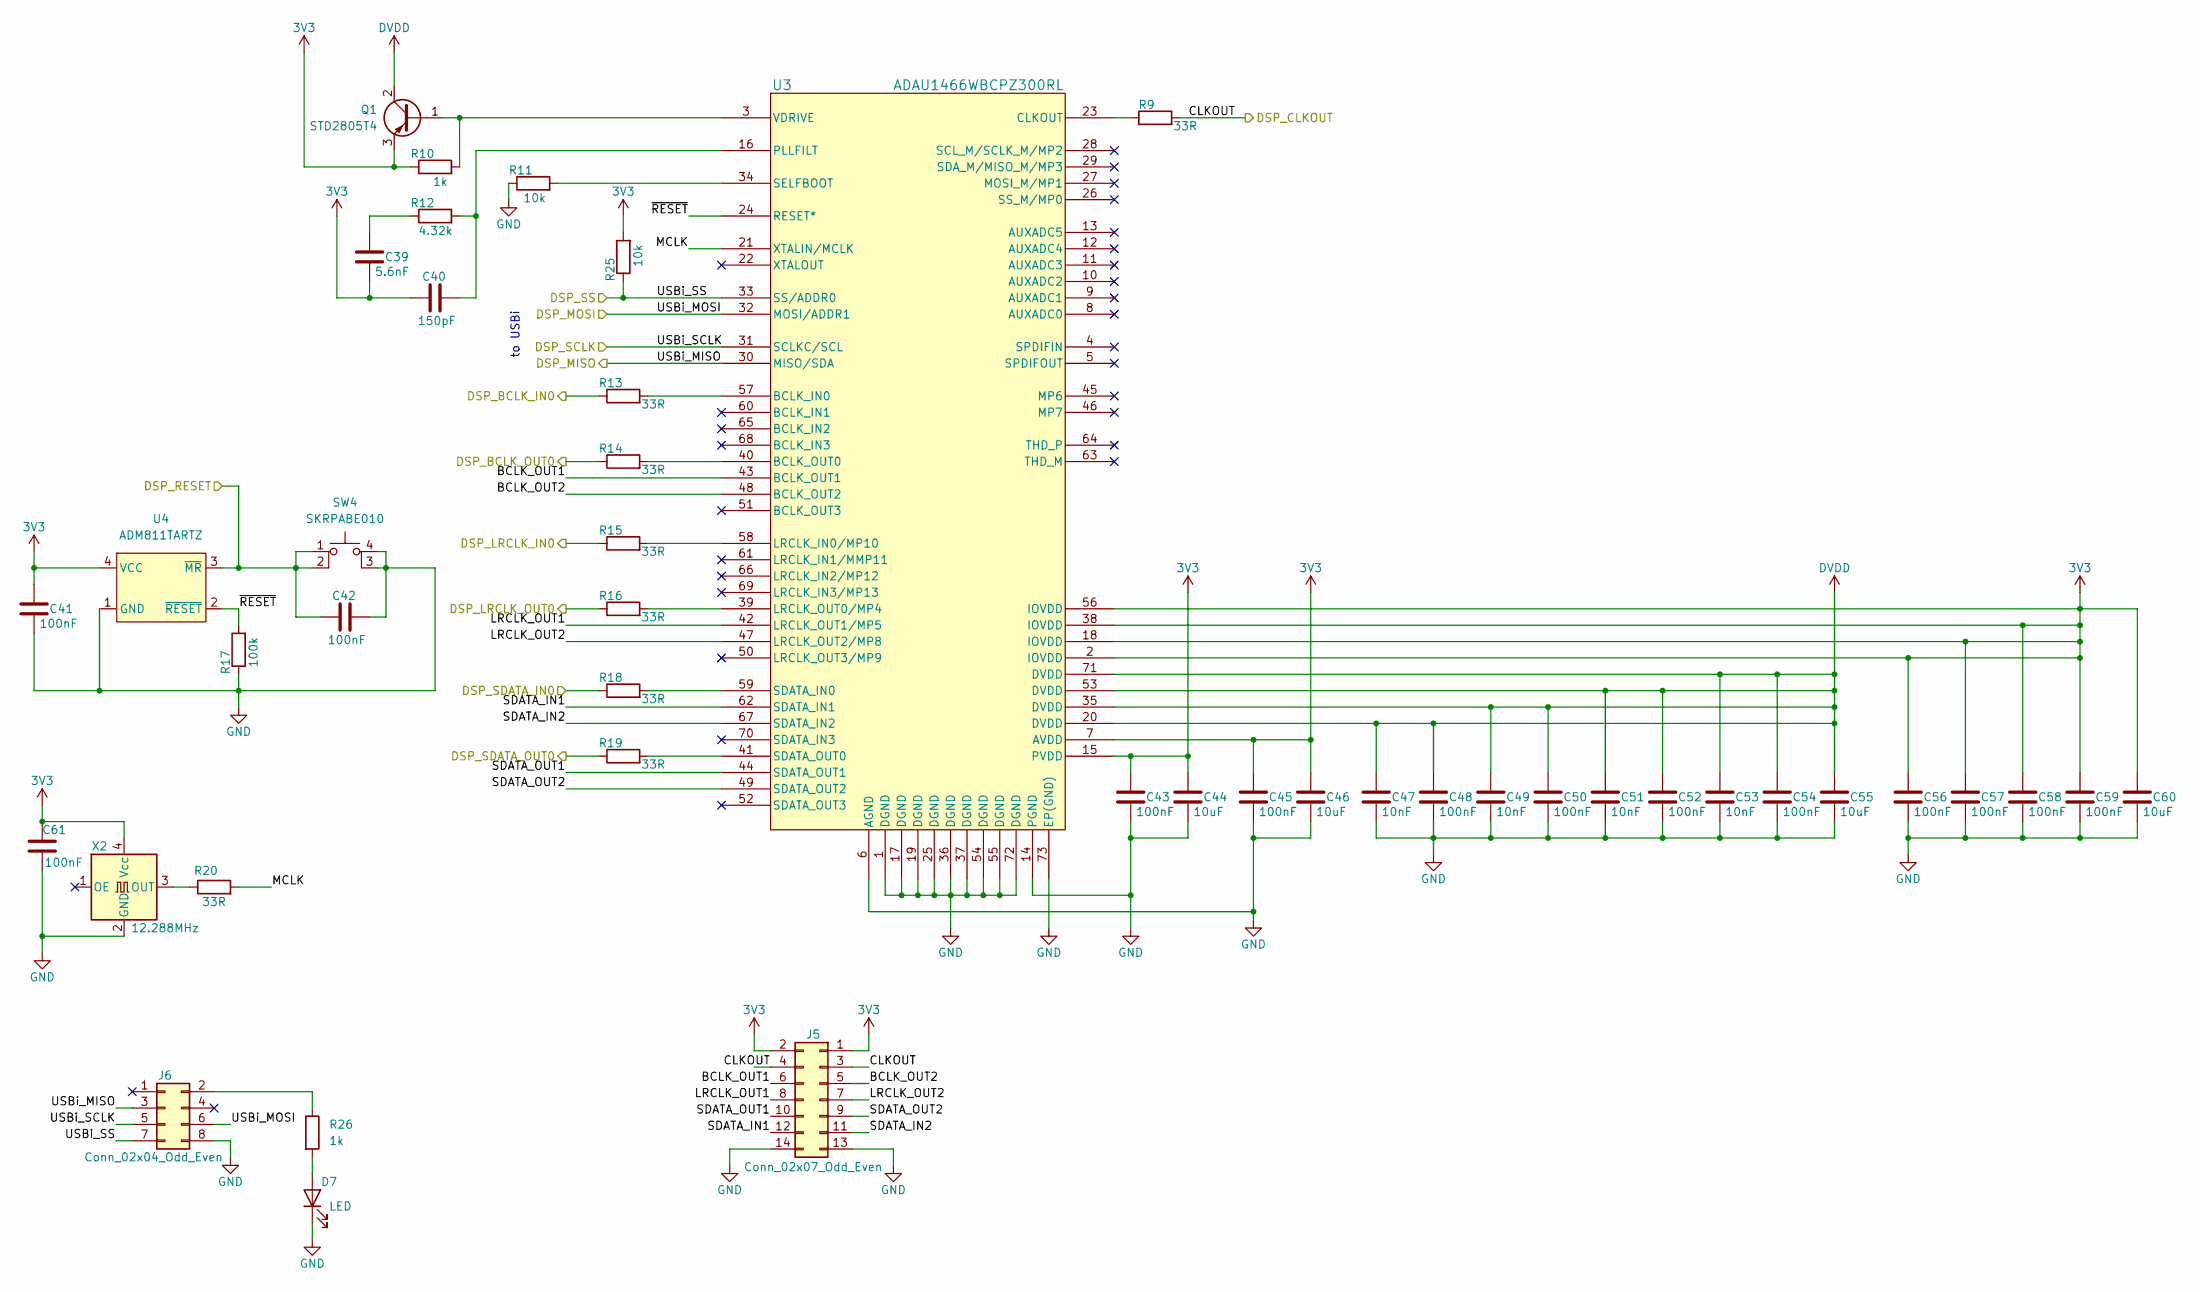
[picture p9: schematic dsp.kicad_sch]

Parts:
C39: 5.6nF; C_0201_0603Metric
C40: 150pF; C_0201_0603Metric
C41, C42, C43, C45, C48, C50, C52, C54, C56, C57, C58, C59: 100nF; C_0201_0603Metric
C44, C46, C55, C60: 10uF; C_0402_1005Metric
C47, C49, C51, C53: 10nF; C_0201_0603Metric
C61: 100nF; C_0402_1005Metric
D7: LED; LED_0603_1608Metric
J5: Conn_02x07_Odd_Even; PinSocket_2x07_P2.54mm_Vertical
J6: Conn_02x04_Odd_Even; PinHeader_2x04_P2.54mm_Vertical
Q1: STD2805T4; TO-252-2
R9, R13, R14, R15, R16, R18, R19, R20: 33R; R_0201_0603Metric
R10, R26: 1k; R_0201_0603Metric
R11, R25: 10k; R_0201_0603Metric
R12: 4.32k; R_0201_0603Metric
R17: 100k; R_0201_0603Metric
SW4: SKRPABE010
U3: ADAU1466WBCPZ300RL; CP_72_6_ADI
U4: ADM811TARTZ; SOT-143
X2: 12.288MHz; Oscillator_SMD_SeikoEpson_SG210-4Pin_2.5x2.0mm

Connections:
3V3: C39.2, C40.1, C41.1, C43.1, C44.1, C45.1, C46.1, C56.1, C57.1, C58.1, C59.1, C60.1, C61.2, J5.1, J5.2, Q1.3 (E), R10.1, R25.2, U3.2 (IOVDD), U3.7 (AVDD), U3.15 (PVDD), U3.18 (IOVDD), U3.38 (IOVDD), U3.56 (IOVDD), U4.4 (VCC), X2.4 (Vcc); also elsewhere on the board
/DSP/BCLK_OUT1: J5.6, U3.43 (BCLK_OUT1)
/DSP/BCLK_OUT2: J5.5, U3.48 (BCLK_OUT2)
/DSP/CLKOUT: J5.3, J5.4, R9.2; also elsewhere on the board
/DSP/DSP_BCLK_IN0: R13.1; also elsewhere on the board
/DSP/DSP_BCLK_OUT0: R14.1; also elsewhere on the board
/DSP/DSP_LRCLK_IN0: R15.1; also elsewhere on the board
/DSP/DSP_LRCLK_OUT0: R16.1; also elsewhere on the board
/DSP/DSP_RESET: C42.1, SW4.1, SW4.2, U4.3 (~MR); also elsewhere on the board
/DSP/DSP_SDATA_IN0: R18.1; also elsewhere on the board
/DSP/DSP_SDATA_OUT0: R19.1; also elsewhere on the board
/DSP/LRCLK_OUT1: J5.8, U3.42 (LRCLK_OUT1/MP5)
/DSP/LRCLK_OUT2: J5.7, U3.47 (LRCLK_OUT2/MP8)
/DSP/MCLK: R20.2, U3.21 (XTALIN/MCLK)
/DSP/SDATA_IN1: J5.12, U3.62 (SDATA_IN1)
/DSP/SDATA_IN2: J5.11, U3.67 (SDATA_IN2)
/DSP/SDATA_OUT1: J5.10, U3.44 (SDATA_OUT1)
/DSP/SDATA_OUT2: J5.9, U3.49 (SDATA_OUT2)
/DSP/USBi_MISO: J6.3, U3.30 (MISO/SDA); also elsewhere on the board
/DSP/USBi_MOSI: J6.6, U3.32 (MOSI/ADDR1); also elsewhere on the board
/DSP/USBi_SCLK: J6.5, U3.31 (SCLKC/SCL); also elsewhere on the board
/DSP/USBi_SS: J6.7, R25.1, U3.33 (SS/ADDR0); also elsewhere on the board
/DSP/~RESET: R17.2, U3.24 (RESET*), U4.2 (~RESET)
DVDD: C47.1, C48.1, C49.1, C50.1, C51.1, C52.1, C53.1, C54.1, C55.1, Q1.2 (C), U3.20 (DVDD), U3.35 (DVDD), U3.53 (DVDD), U3.71 (DVDD)
GND: C41.2, C42.2, C43.2, C44.2, C45.2, C46.2, C47.2, C48.2, C49.2, C50.2, C51.2, C52.2, C53.2, C54.2, C55.2, C56.2, C57.2, C58.2, C59.2, C60.2, C61.1, D7.1 (K), J5.13, J5.14, J6.8, R11.1, R17.1, SW4.3 (K), SW4.4 (A), U3.1 (DGND), U3.6 (AGND), U3.14 (PGND), U3.17 (DGND), U3.19 (DGND), U3.25 (DGND), U3.36 (DGND), U3.37 (DGND), U3.54 (DGND), U3.55 (DGND), U3.72 (DGND), U3.73 (EP(GND)), U4.1 (GND), X2.2 (GND); also elsewhere on the board
unnamed: C39.1, R12.1
unnamed: D7.2 (A), R26.2
unnamed: J6.2, R26.1
unnamed: Q1.1 (B), R10.2, U3.3 (VDRIVE)
unnamed: R13.2, U3.57 (BCLK_IN0)
unnamed: R14.2, U3.40 (BCLK_OUT0)
unnamed: R9.1, U3.23 (CLKOUT)
unnamed: R15.2, U3.58 (LRCLK_IN0/MP10)
unnamed: R16.2, U3.39 (LRCLK_OUT0/MP4)
unnamed: C40.2, R12.2, U3.16 (PLLFILT)
unnamed: R18.2, U3.59 (SDATA_IN0)
unnamed: R19.2, U3.41 (SDATA_OUT0)
unnamed: R11.2, U3.34 (SELFBOOT)
unnamed: R20.1, X2.3 (OUT)

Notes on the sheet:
to USBi

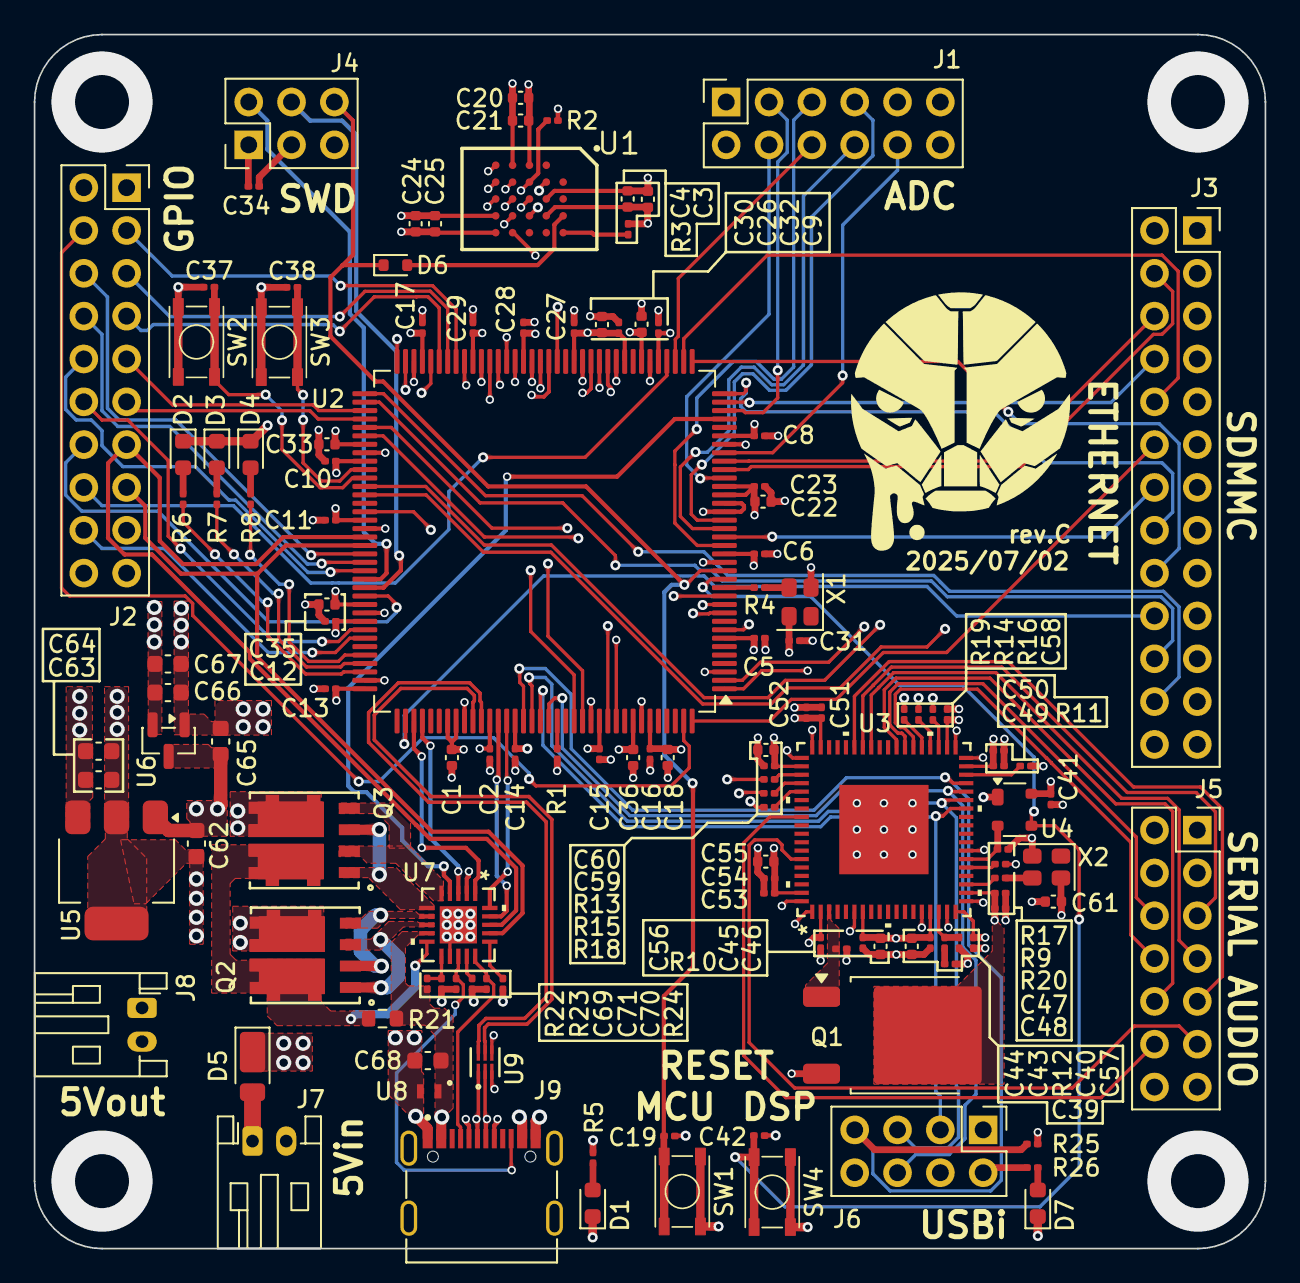
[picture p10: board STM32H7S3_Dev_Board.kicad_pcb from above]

Board: 6 copper layers, 73.0 x 72.0 mm, 130 parts (0 on the bottom side), 135 nets.

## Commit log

2026-03-09 Add .gitignore for KiCad
    Ignores KiCad temporary files, backups, and build artifacts to keep the repository clean.
2026-03-09 Update .gitignore for STM32H7S3 Dev Board backups
    Ignores backup directories for the STM32H7S3 development board subprojects to keep the repository clean.
2026-03-09 Add KiCad project files.
    [STM32H7S3_Dev_Board.kicad_pcb, STM32H7S3_Dev_Board.kicad_sch, dsp.kicad_sch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]
2026-03-09 Update README with board details and specifications
    Added detailed information about the STM32H7S3 development board, including specifications, purchasing information, pinout, size, and licensing.
2026-03-09 Add Rev C schematic PDF
    Adds the PDF version of the STM32H7S3 development board revision C schematic for easy reference.
2026-03-10 Enhance README with links in specifications
    Updated specifications section to include hyperlinks for STM32H7S3Z8T and ADAU1466.
2026-03-12 Change the 3D model data path settings.
    [STM32H7S3_Dev_Board.kicad_pcb]
